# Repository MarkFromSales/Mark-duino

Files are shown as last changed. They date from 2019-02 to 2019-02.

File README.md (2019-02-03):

# Mark-duino
Playing around with my own Arduino build, purely academic really. Basically I wanted to keep the same setup as a typical Arduino Nano but expand the GPIO dramatically. The MCP23017-E/SP is used a lot in my other projects and works very well for my hobbyist needs.

## Attributions and Thanks
- ATMega328 outside of Arduino Uno - https://dronebotworkshop.com/arduino-uno-atmega328/
- Multi-tasking the Arduino - https://learn.adafruit.com/multi-tasking-the-arduino-part-1?view=all
- MCP23017 I2C GPIO expander - https://www.adafruit.com/product/732
- KiCad tutorials and much more - https://contextualelectronics.com/
- KiCad interactive BOM tool video - https://www.youtube.com/watch?v=H9WsmhtoH8E
- KiCad interactive BOM tool location - https://github.com/openscopeproject/InteractiveHtmlBom

## Bill of Materials
Important note: I chose many of these components because I already had a pile of them from other projects. The 100nF capacitor on C1 is a great example of where I had an existing part and chose that over a better, more consistent footprint. Later version of this project will use more consistent (mostly 1206) footprints.

The screw terminals drive the overall price of the project fairly high if you don't already have these on hand. Substitute them out with a regular 2.54mm pin header or socket strips to cut cost if desired.

You can import this CSV directly into Digi-Key (www.digikey.com)
https://github.com/MarkFromSales/Mark-duino/blob/master/mark-duino_bom.csv

## MCP Addresses
The MCP A0, A1, and A2 pins are not directly connected in the PCB and have solder jumpers instead to allow flexibility in addressing. 

```
addr 0 = A2 low,  A1 low,  A0 low  000
addr 1 = A2 low,  A1 low,  A0 high 001
addr 2 = A2 low,  A1 high, A0 low  010
addr 3 = A2 low,  A1 high, A0 high 011
addr 4 = A2 high, A1 low,  A0 low  100
addr 5 = A2 high, A1 low,  A0 high 101
addr 6 = A2 high, A1 high, A0 low  110
addr 7 = A2 high, A1 high, A0 high 111
```

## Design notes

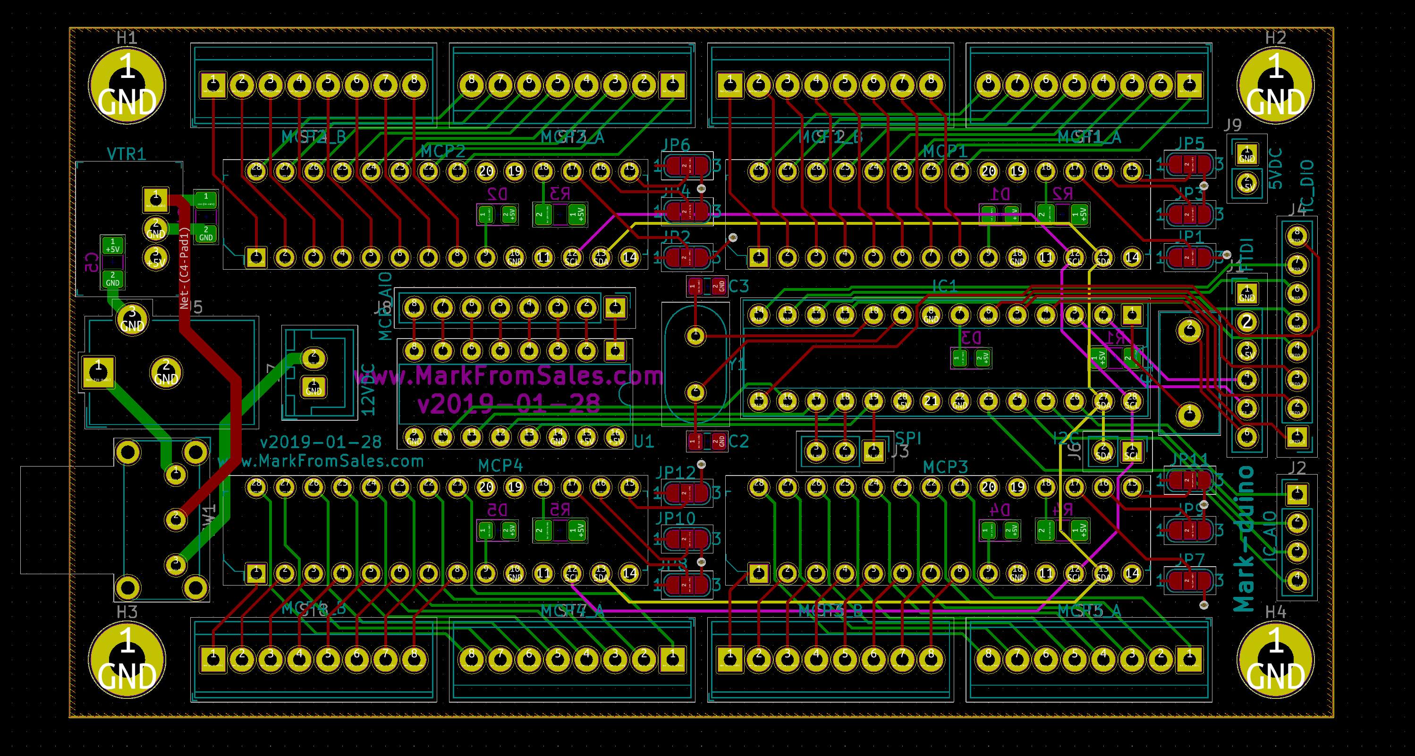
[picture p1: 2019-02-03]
Mark-duino_PCB_Screenshot.PNG

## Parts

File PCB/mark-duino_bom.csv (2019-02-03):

Manufacturer Part Number | Manufacturer | Digi-Key Part Number | Packaging | Quantity | Description
ATMEGA328P-PU | Microchip Technology | ATMEGA328P-PU-ND | Tube | 1 | IC MCU 8BIT 32KB FLASH 28DIP
CL21C220JB61PNC | Samsung Electro-Mechanics | 1276-2605-1-ND | Cut Tape (CT) | 2 | CAP CER 22PF 50V C0G/NP0 0805
CL31A106KBHNNNE | Samsung Electro-Mechanics | 1276-2876-1-ND | Cut Tape (CT) | 1 | CAP CER 10UF 50V X5R 1206
CL31A226KOHNNNE | Samsung Electro-Mechanics | 1276-3048-1-ND | Cut Tape (CT) | 1 | CAP CER 22UF 16V X5R 1206
QYX2A104JTP | Nichicon | 493-3500-ND | Bulk | 1 | CAP FILM 0.1UF 5% 100VDC RADIAL
RC3216F103CS | Samsung Electro-Mechanics | 1276-5742-1-ND | Cut Tape (CT) | 5 | RES SMD 10K OHM 1% 1/4W 1206
SD0805S020S1R0 | AVX Corporation | 478-7800-1-ND | Cut Tape (CT) | 5 | DIODE SCHOTTKY 20V 1A 0805
MCP3008-I/P | Microchip Technology | MCP3008-I/P-ND | Tube | 1 | IC ADC 10BIT 2.7V 8CH SPI 16DIP
ECS-160-20-46X | ECS Inc. | XC1759-ND | Bulk | 1 | CRYSTAL 16.0000MHZ 20PF T/H
EG1224 | E-Switch | EG2585-ND | Bulk | 1 | SWITCH SLIDE SPDT 500MA 15V
V7805-1000 | CUI Inc. | 102-1715-ND | Tube | 1 | DC DC CONVERTER 5V 5W
MCP23017-E/SP | Microchip Technology | MCP23017-E/SP-ND | Tube | 4 | IC I/O EXPANDER I2C 16B 28SDIP
282834-8 | TE Connectivity AMP Connectors | A98338-ND | Box | 8 | TERM BLK 8P SIDE ENT 2.54MM PCB
PJ-102AH | CUI Inc. | CP-102AH-ND | Tray | 1 | CONN PWR JACK 2X5.5MM SOLDER
B2B-XH-A-GU | JST Sales America Inc. | 455-2946-ND | Bulk | 1 | CONN HEADER VERT 2POS 2.5MM
SXH-001T-P0.6 | JST Sales America Inc. | 455-1135-1-ND | Cut Tape (CT) | 2 | CONN SOCKET 22-28AWG CRIMP TIN
XHP-2 | JST Sales America Inc. | 455-2266-ND | Bulk | 1 | CONN HOUSING 2.5MM 2POS
HDR100IMP40M-G-V-TH | Chip Quik Inc. | HDR100IMP40M-G-V-TH-ND | Bulk | 1 | CONN HEADER VERT 40POS 2.54MM

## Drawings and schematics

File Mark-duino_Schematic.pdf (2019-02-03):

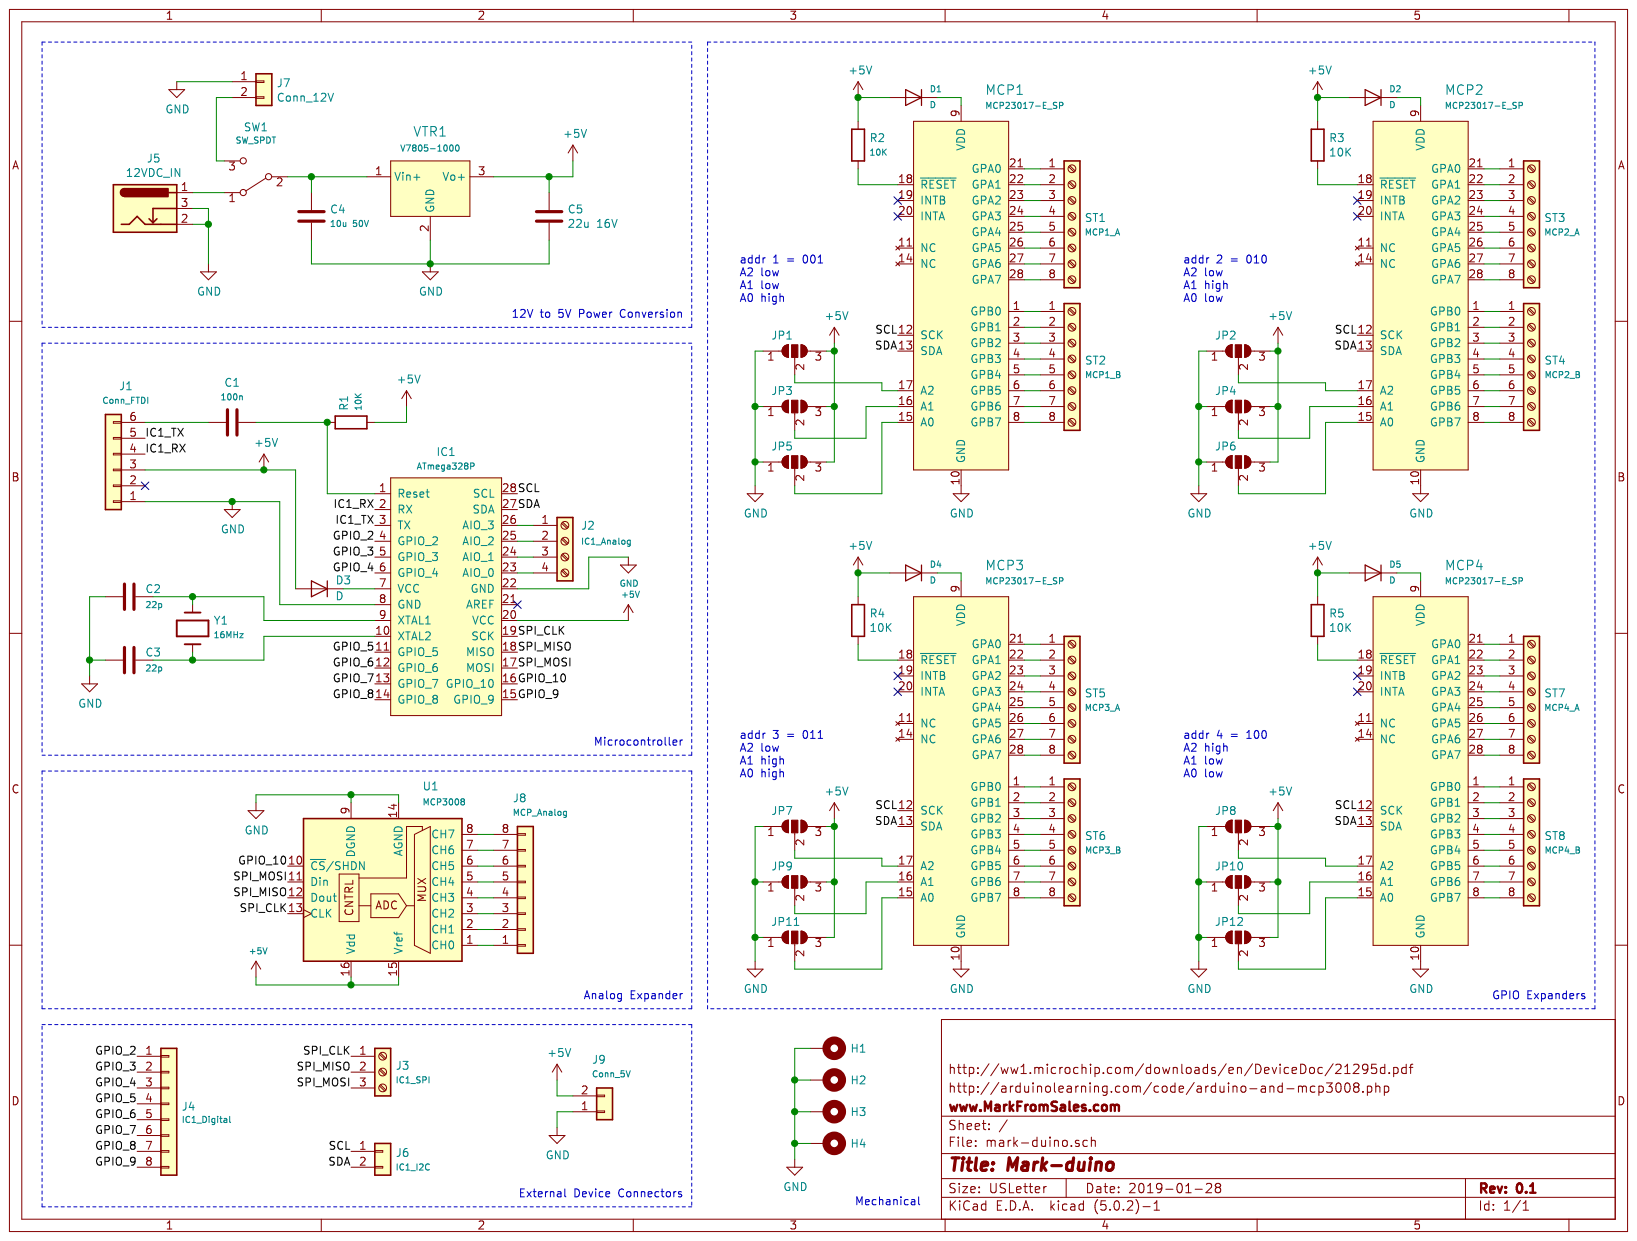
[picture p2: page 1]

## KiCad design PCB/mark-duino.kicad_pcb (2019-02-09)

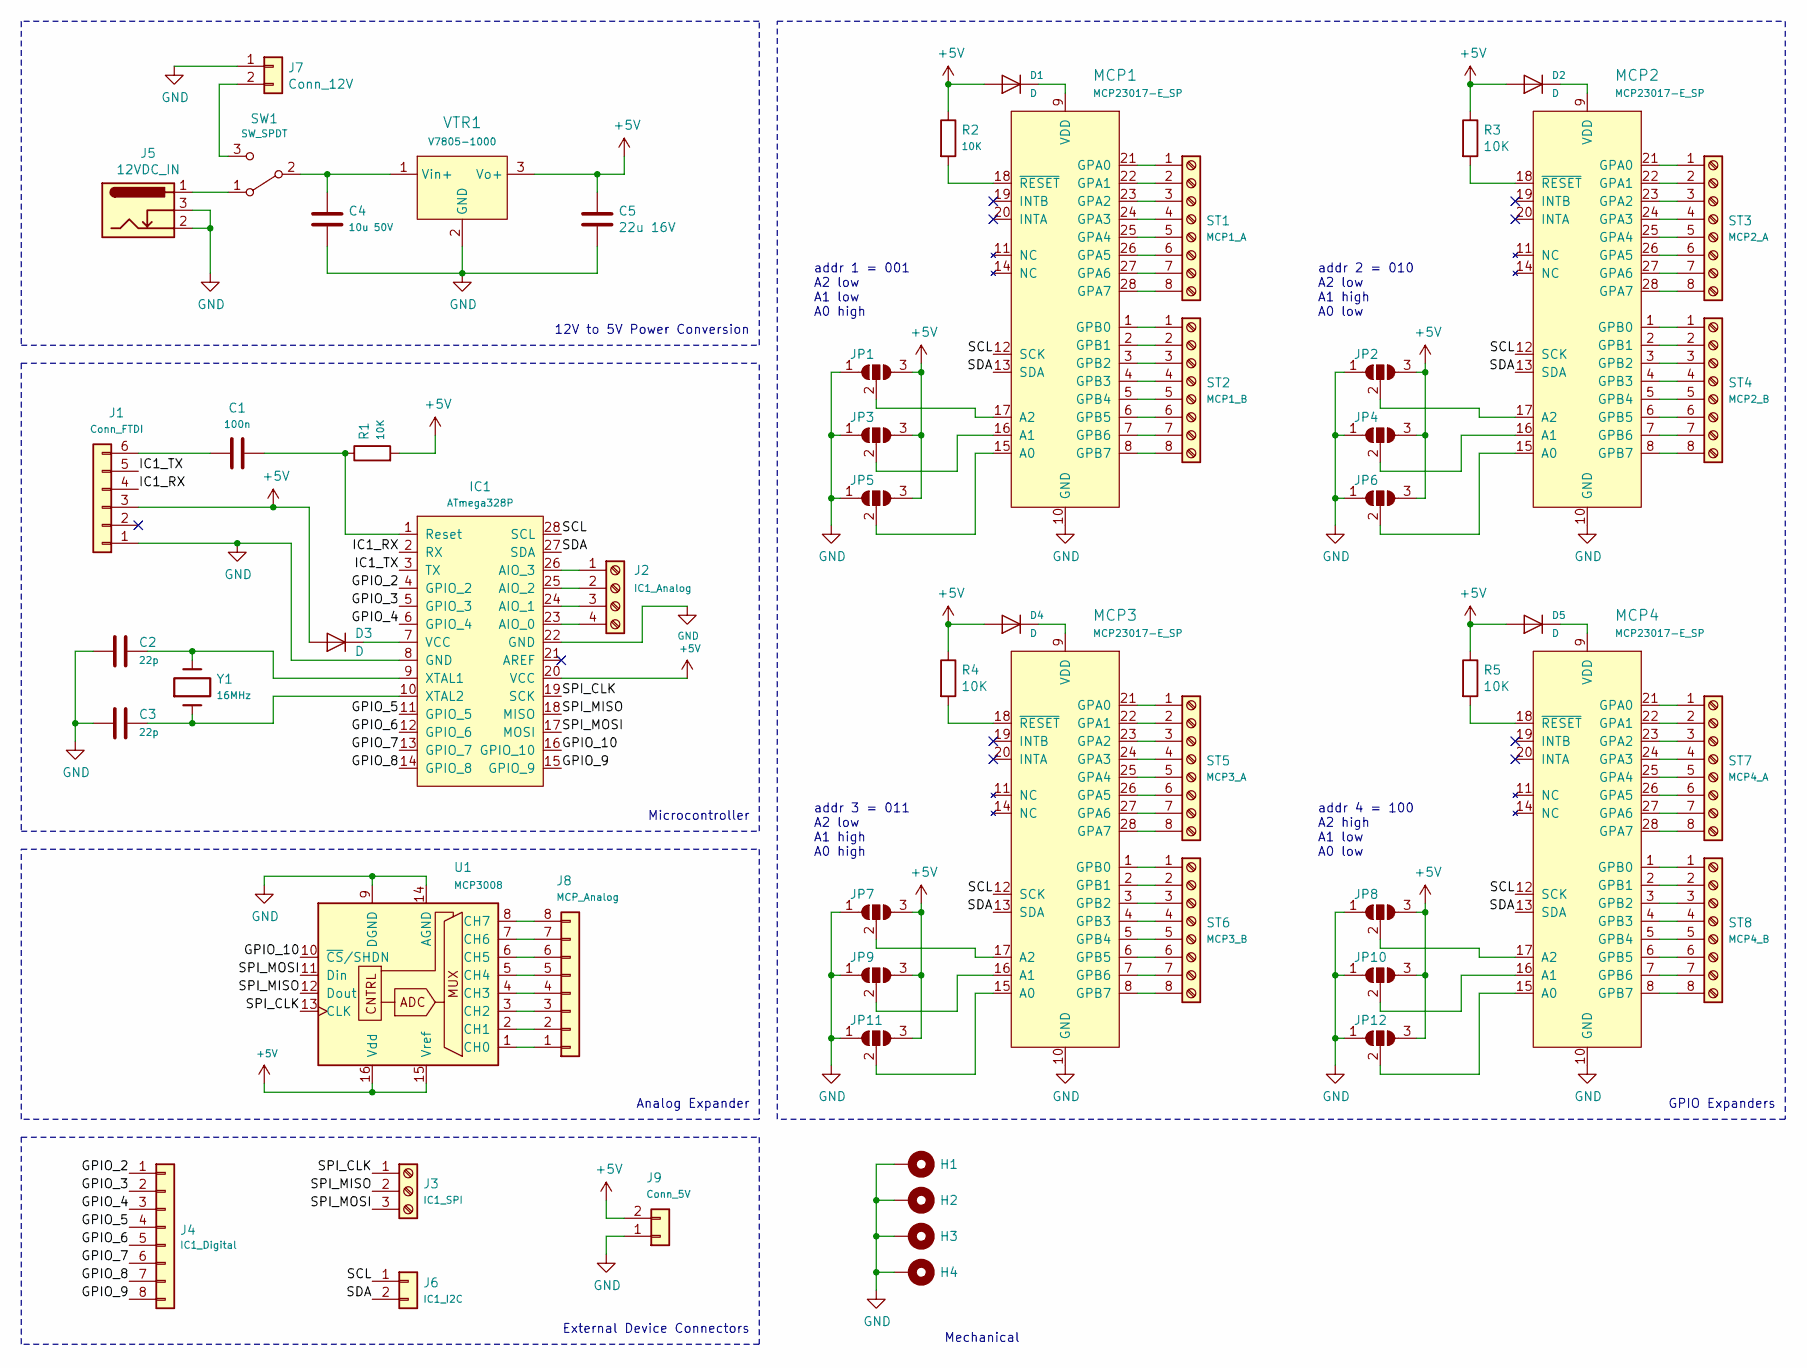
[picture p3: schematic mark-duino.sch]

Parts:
C1: 100n; C_Disc_D10.5mm_W5.0mm_P7.50mm
C2, C3: 22p; C_0805_2012Metric_Pad1.15x1.40mm_HandSolder
C4: 10u 50V; C_1206_3216Metric_Pad1.42x1.75mm_HandSolder
C5: 22u 16V; C_1206_3216Metric_Pad1.42x1.75mm_HandSolder
D1, D2, D3, D4, D5: D; D_0805_2012Metric_Pad1.15x1.40mm_HandSolder
H1, H2, H3, H4: MountingHole_Pad; MountingHole_3.2mm_M3_Pad
IC1: ATmega328P; DIP-28_W7.62mm_Socket
J1: Conn_FTDI; PinHeader_1x06_P2.54mm_Vertical
J2: IC1_Analog; PinHeader_1x04_P2.54mm_Vertical
J3: IC1_SPI; PinHeader_1x03_P2.54mm_Vertical
J4: IC1_Digital; PinHeader_1x08_P2.54mm_Vertical
J5: 12VDC_IN; BarrelJack_CUI_PJ-102AH_Horizontal
J6: IC1_I2C; PinHeader_1x02_P2.54mm_Vertical
J7: Conn_12V; JST_XH_B02B-XH-A_1x02_P2.50mm_Vertical
J8: MCP_Analog; PinHeader_1x08_P2.54mm_Vertical
J9: Conn_5V; PinHeader_1x02_P2.54mm_Vertical
JP1, JP2, JP3, JP4, JP5, JP6, JP7, JP8, JP9, JP10, JP11, JP12: SolderJumper_3_Open; SolderJumper-3_P1.3mm_Open_RoundedPad1.0x1.5mm_NumberLabels
MCP1, MCP2, MCP3, MCP4: MCP23017-E_SP; DIP-28_W7.62mm; MPN MCP23017-E/SP; Digi-Key_PN MCP23017-E/SP-ND
R1, R2, R3, R4, R5: 10K; C_1206_3216Metric_Pad1.42x1.75mm_HandSolder
ST1: MCP1_A; TerminalBlock_TE_282834-8_1x08_P2.54mm_Horizontal
ST2: MCP1_B; TerminalBlock_TE_282834-8_1x08_P2.54mm_Horizontal
ST3: MCP2_A; TerminalBlock_TE_282834-8_1x08_P2.54mm_Horizontal
ST4: MCP2_B; TerminalBlock_TE_282834-8_1x08_P2.54mm_Horizontal
ST5: MCP3_A; TerminalBlock_TE_282834-8_1x08_P2.54mm_Horizontal
ST6: MCP3_B; TerminalBlock_TE_282834-8_1x08_P2.54mm_Horizontal
ST7: MCP4_A; TerminalBlock_TE_282834-8_1x08_P2.54mm_Horizontal
ST8: MCP4_B; TerminalBlock_TE_282834-8_1x08_P2.54mm_Horizontal
SW1: SW_SPDT; SW_E-Switch_EG1224_SPDT_Angled
U1: MCP3008; DIP-16_W7.62mm
VTR1: V7805-1000; 3-SIP_Module_V7805-1000; MPN V7805-1000; Digi-Key_PN 102-1715-ND
Y1: 16MHz; Resonator-2Pin_W10.0mm_H5.0mm

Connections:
/GPIO_2: IC1.4 (GPIO_2), J4.1
/GPIO_3: IC1.5 (GPIO_3), J4.2
/GPIO_4: IC1.6 (GPIO_4), J4.3
/GPIO_5: IC1.11 (GPIO_5), J4.4
/GPIO_6: IC1.12 (GPIO_6), J4.5
/GPIO_7: IC1.13 (GPIO_7), J4.6
/GPIO_8: IC1.14 (GPIO_8), J4.7
/GPIO_9: IC1.15 (GPIO_9), J4.8
/GPIO_10: IC1.16 (GPIO_10), U1.10 (~CS~/SHDN)
/IC1_RX: IC1.2 (RX), J1.4
/IC1_TX: IC1.3 (TX), J1.5
/SCL: IC1.28 (SCL), J6.1, MCP1.12 (SCK), MCP2.12 (SCK), MCP3.12 (SCK), MCP4.12 (SCK)
/SDA: IC1.27 (SDA), J6.2, MCP1.13 (SDA), MCP2.13 (SDA), MCP3.13 (SDA), MCP4.13 (SDA)
/SPI_CLK: IC1.19 (SCK), J3.1, U1.13 (CLK)
/SPI_MISO: IC1.18 (MISO), J3.2, U1.12 (Dout)
/SPI_MOSI: IC1.17 (MOSI), J3.3, U1.11 (Din)
GND: C2.2, C3.2, C4.2, C5.2, H1.1, H2.1, H3.1, H4.1, IC1.8 (GND), IC1.22 (GND), J1.1, J5.2, J5.3, J7.1, J9.1, JP1.1 (A), JP2.1 (A), JP3.1 (A), JP4.1 (A), JP5.1 (A), JP6.1 (A), JP7.1 (A), JP8.1 (A), JP9.1 (A), JP10.1 (A), JP11.1 (A), JP12.1 (A), MCP1.10 (GND), MCP2.10 (GND), MCP3.10 (GND), MCP4.10 (GND), U1.9 (DGND), U1.14 (AGND), VTR1.2 (GND)
unnamed: C1.2, J1.6
unnamed: C2.1, IC1.9 (XTAL1), Y1.2
unnamed: C3.1, IC1.10 (XTAL2), Y1.1
unnamed: C4.1, SW1.2 (B), VTR1.1 (Vin+)
unnamed: D1.1 (K), MCP1.9 (VDD)
unnamed: D2.1 (K), MCP2.9 (VDD)
unnamed: D3.1 (K), IC1.7 (VCC)
unnamed: D4.1 (K), MCP3.9 (VDD)
unnamed: D5.1 (K), MCP4.9 (VDD)
unnamed: IC1.23 (AIO_0), J2.4
unnamed: IC1.24 (AIO_1), J2.3
unnamed: IC1.25 (AIO_2), J2.2
unnamed: IC1.26 (AIO_3), J2.1
unnamed: J5.1, SW1.1 (A)
unnamed: J7.2, SW1.3 (C)
unnamed: J8.1, U1.1 (CH0)
unnamed: J8.2, U1.2 (CH1)
unnamed: J8.3, U1.3 (CH2)
unnamed: J8.4, U1.4 (CH3)
unnamed: J8.5, U1.5 (CH4)
unnamed: J8.6, U1.6 (CH5)
unnamed: J8.7, U1.7 (CH6)
unnamed: J8.8, U1.8 (CH7)
unnamed: JP1.2 (C), MCP1.17 (A2)
unnamed: JP2.2 (C), MCP2.17 (A2)
unnamed: JP3.2 (C), MCP1.16 (A1)
unnamed: JP4.2 (C), MCP2.16 (A1)
unnamed: JP5.2 (C), MCP1.15 (A0)
unnamed: JP6.2 (C), MCP2.15 (A0)
unnamed: JP7.2 (C), MCP3.17 (A2)
unnamed: JP8.2 (C), MCP4.17 (A2)
unnamed: JP9.2 (C), MCP3.16 (A1)
unnamed: JP10.2 (C), MCP4.16 (A1)
unnamed: JP11.2 (C), MCP3.15 (A0)
unnamed: JP12.2 (C), MCP4.15 (A0)
unnamed: MCP1.1 (GPB0), ST2.1
unnamed: MCP1.2 (GPB1), ST2.2
unnamed: MCP1.3 (GPB2), ST2.3
unnamed: MCP1.4 (GPB3), ST2.4
unnamed: MCP1.5 (GPB4), ST2.5
unnamed: MCP1.6 (GPB5), ST2.6
unnamed: MCP1.7 (GPB6), ST2.7
unnamed: MCP1.8 (GPB7), ST2.8
unnamed: MCP1.18 (~RESET), R2.2
unnamed: MCP1.21 (GPA0), ST1.1
unnamed: MCP1.22 (GPA1), ST1.2
unnamed: MCP1.23 (GPA2), ST1.3
unnamed: MCP1.24 (GPA3), ST1.4
unnamed: MCP1.25 (GPA4), ST1.5
unnamed: MCP1.26 (GPA5), ST1.6
unnamed: MCP1.27 (GPA6), ST1.7
unnamed: MCP1.28 (GPA7), ST1.8
unnamed: MCP2.1 (GPB0), ST4.1
unnamed: MCP2.2 (GPB1), ST4.2
unnamed: MCP2.3 (GPB2), ST4.3
unnamed: MCP2.4 (GPB3), ST4.4
unnamed: MCP2.5 (GPB4), ST4.5
unnamed: MCP2.6 (GPB5), ST4.6
unnamed: MCP2.7 (GPB6), ST4.7
unnamed: MCP2.8 (GPB7), ST4.8
unnamed: MCP2.18 (~RESET), R3.2
unnamed: MCP2.21 (GPA0), ST3.1
unnamed: MCP2.22 (GPA1), ST3.2
unnamed: MCP2.23 (GPA2), ST3.3
unnamed: MCP2.24 (GPA3), ST3.4
unnamed: MCP2.25 (GPA4), ST3.5
unnamed: MCP2.26 (GPA5), ST3.6
unnamed: MCP2.27 (GPA6), ST3.7
unnamed: MCP2.28 (GPA7), ST3.8
unnamed: MCP3.1 (GPB0), ST6.1
unnamed: MCP3.2 (GPB1), ST6.2
unnamed: MCP3.3 (GPB2), ST6.3
unnamed: MCP3.4 (GPB3), ST6.4
unnamed: MCP3.5 (GPB4), ST6.5
unnamed: MCP3.6 (GPB5), ST6.6
unnamed: MCP3.7 (GPB6), ST6.7
unnamed: MCP3.8 (GPB7), ST6.8
unnamed: MCP3.18 (~RESET), R4.2
unnamed: MCP3.21 (GPA0), ST5.1
unnamed: MCP3.22 (GPA1), ST5.2
unnamed: MCP3.23 (GPA2), ST5.3
unnamed: MCP3.24 (GPA3), ST5.4
unnamed: MCP3.25 (GPA4), ST5.5
unnamed: MCP3.26 (GPA5), ST5.6
unnamed: MCP3.27 (GPA6), ST5.7
unnamed: MCP3.28 (GPA7), ST5.8
unnamed: MCP4.1 (GPB0), ST8.1
unnamed: MCP4.2 (GPB1), ST8.2
unnamed: MCP4.3 (GPB2), ST8.3
unnamed: MCP4.4 (GPB3), ST8.4
unnamed: MCP4.5 (GPB4), ST8.5
unnamed: MCP4.6 (GPB5), ST8.6
unnamed: MCP4.7 (GPB6), ST8.7
unnamed: MCP4.8 (GPB7), ST8.8
unnamed: MCP4.18 (~RESET), R5.2
unnamed: MCP4.21 (GPA0), ST7.1
unnamed: MCP4.22 (GPA1), ST7.2
unnamed: MCP4.23 (GPA2), ST7.3
unnamed: MCP4.24 (GPA3), ST7.4
unnamed: MCP4.25 (GPA4), ST7.5
unnamed: MCP4.26 (GPA5), ST7.6
unnamed: MCP4.27 (GPA6), ST7.7
unnamed: MCP4.28 (GPA7), ST7.8

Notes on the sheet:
GPIO Expanders
12V to 5V Power Conversion
Microcontroller
Analog Expander
External Device Connectors
Mechanical
addr 1 = 001 A2 low A1 low A0 high
addr 2 = 010 A2 low A1 high A0 low
addr 3 = 011 A2 low A1 high A0 high
addr 4 = 100 A2 high A1 low A0 low

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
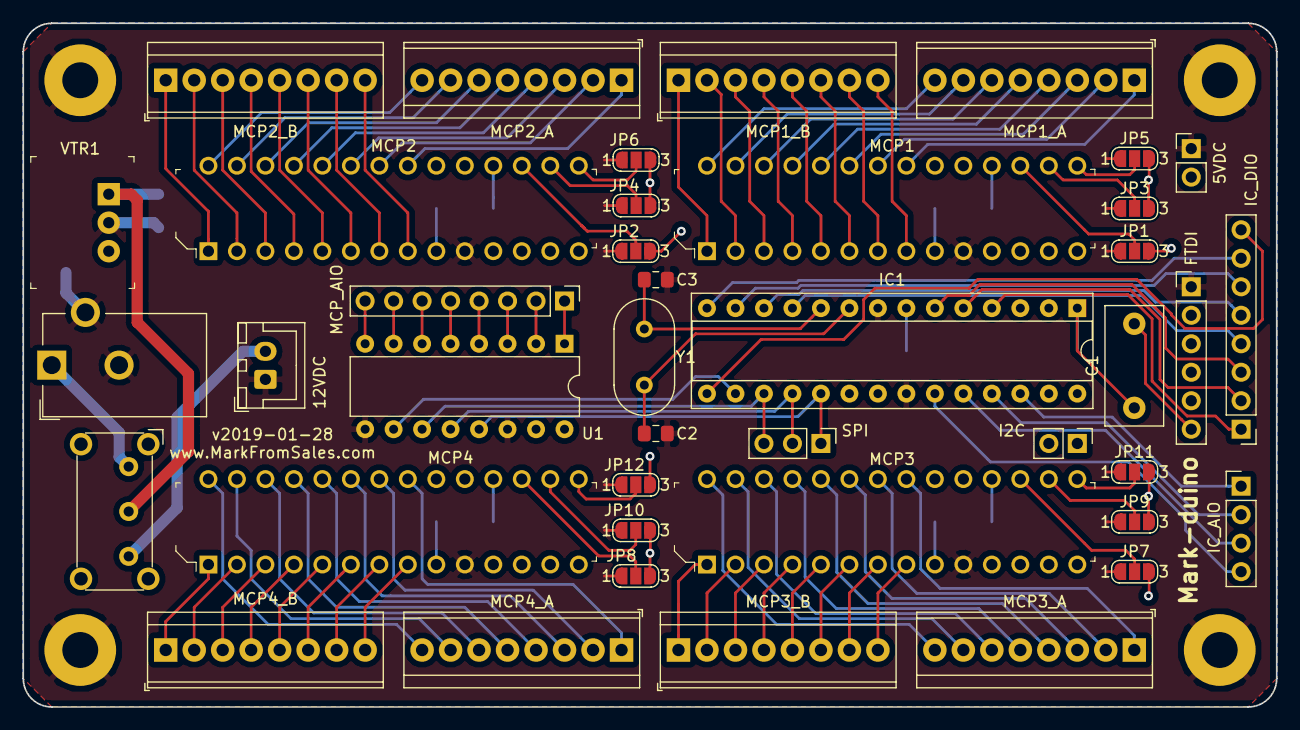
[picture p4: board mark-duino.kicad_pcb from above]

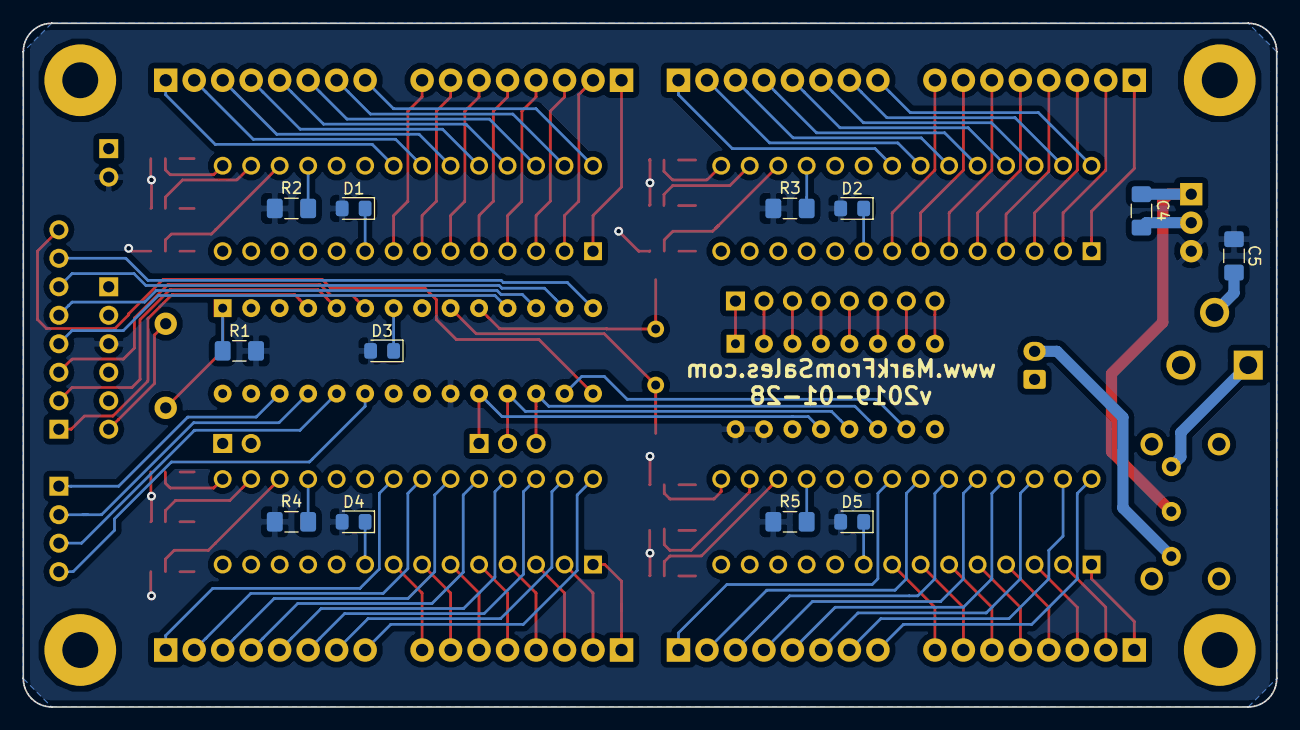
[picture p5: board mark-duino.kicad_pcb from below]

Board: 4 copper layers, 111.8 x 61.0 mm, 57 parts (12 on the bottom side), 122 nets.

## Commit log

2019-02-02 Initial upload
    [mark-duino.kicad_pcb, mark-duino.sch]
2019-02-03 Cleaned up and updated documentation
    [mark-duino.sch]
2019-02-09 Rounded corners
    [mark-duino.kicad_pcb]
2019-02-13 Updated structure
    [mark-duino.kicad_pcb, mark-duino.sch, mark-duino_bom.csv]
